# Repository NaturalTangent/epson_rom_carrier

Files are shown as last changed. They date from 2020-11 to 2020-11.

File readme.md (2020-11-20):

# Epson PX-8 / PX-4 ROM Carrier

Andy Anderson 2020

This is a 3d printable ROM carrier for mounting ROMs in the capsule sockets of the Epson PX-8 and PX-4 portable computers.

You may need to tweak some of the measurements (near the top of RomCapsule.scad) if your 3d printer performs differently to mine, or your ROM sockets have different tollerances (I have 2 PX-8 and the fit is tighter on one of them). It can help to chamfer the sharp edges on the bottom printed carrier with a scalpel.

The STL file can be generated by loading RomCapsule.scad into OpenSCAD (https://www.openscad.org/).

When printing you will need to enable supports to allow the horizontal tabs to print successfully.

For info:

One of my PX-8 has the following part numbers;

* ROM socket: 8878 28S MOLEX 5
* ROM carrier: MOLEX 5 8878

The other has;

* ROM socket: 5500 28 8878 MXJ 2
* ROM carrier: MXJ 4 5501

The MOLEX carrier is a tight fit in the MXJ socket. I based the measurement for this reproduction on the MXJ carrier.

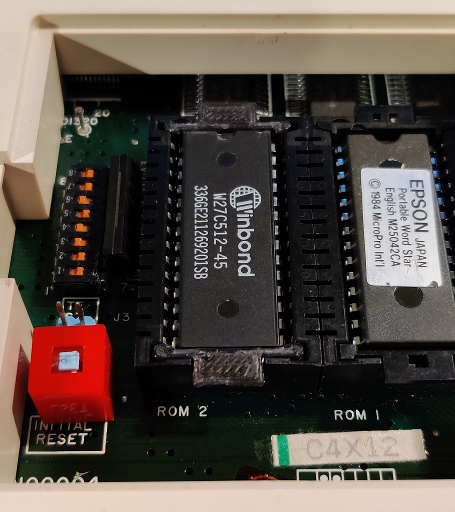
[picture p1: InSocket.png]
In Socket

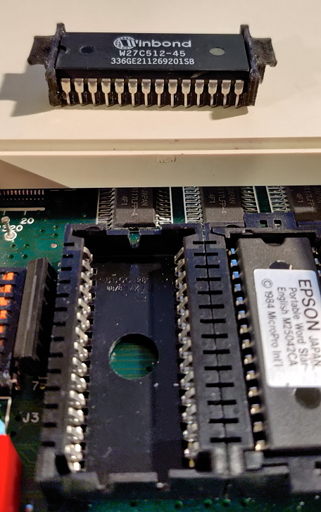
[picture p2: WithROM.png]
With ROM

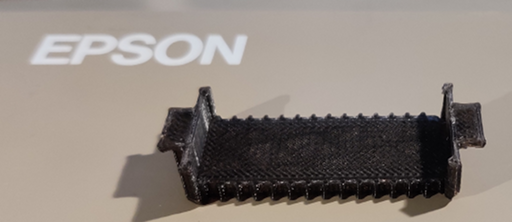
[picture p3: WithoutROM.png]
Without ROM


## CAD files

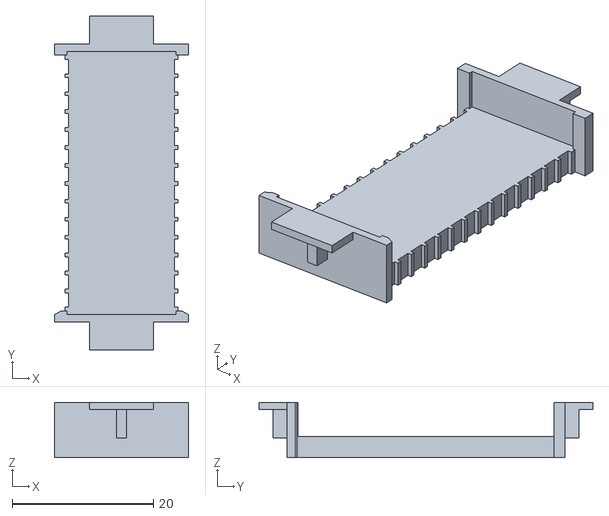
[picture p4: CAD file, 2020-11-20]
RomCapsule.stl
19.0 x 47.3 x 7.80

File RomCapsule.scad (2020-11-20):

/*
This is a 3d printable ROM carrier for mounting ROMs in the capsule sockets of the Epson PX-8 and PX-4 computers.

When printing you will need to enable supports to allow the horizontal tabs to print successfully.

Andy Anderson 2020
*/

// Dimension of the flat base
base_width = 16.0;
base_depth = 37.3;
base_height = 3;

// The distance between centres of the IC legs
pin_spacing = 2.54;

// Count of pins per side of the IC
pin_count = 14;

// IC leg dimension
pin_width = 2;
pin_clearance = 0.1;


// The gap cut into the base for each IC leg
pin_cut_depth = 0.5;
pin_gap = pin_width + pin_clearance;

// The size of the non-cut space between each IC leg
pin_non_gap = pin_spacing - pin_gap;

// The total base length that needs cuts for IC legs (easier to centre it)
active_pin_area = ((pin_count-1) * pin_non_gap) + (pin_count * pin_gap);
pin_start = (base_depth - active_pin_area)/2;

// The end wall dimensions
end_width = 19;
end_depth = 1;
end_height = 7.8;

// End wall strengthening bar dimensions
strength_width = 1.8;
strength_depth = 1.5;
strength_height = end_height;

// The dimensions of the flat tab on top of each end wall
tab_width = 9;
tab_depth = 4;
tab_height = 1;

// The dimensions of the locating tangs on each end wall
tang_width = 1.4;
tang_depth = 2;
tang_height = 4;


module base()
{
    difference()
    {
        cube([base_width, base_depth, base_height]);
        for(leg = [0: 1: pin_count-1])
        {
            translate([-pin_cut_depth, pin_start+(leg*pin_spacing), -1])
                cube([pin_cut_depth*2, pin_width, base_height+2]);
            
            translate([base_width-pin_cut_depth, pin_start+(leg*pin_spacing), -1])
                cube([pin_cut_depth*2, pin_width, base_height+2]);
        }
    }
}

// End with single tang and chamfered strengtheners
module end1()
{
    union()
    {
        // End wall
        cube([end_width, end_depth, end_height]);
        
        // Wall strength - with hacky chamfer
        hull()
        {
            cube([strength_width/2, end_depth, strength_height]); 
            translate([strength_width/2, 0, 0])
                cube([strength_width/2, strength_depth, strength_height]);        
        }
        
        hull()
        {
            translate([end_width-strength_width/2, 0, 0])
                cube([strength_width/2, end_depth, strength_height]); 
            translate([end_width-strength_width, 0, 0])
                cube([strength_width/2, strength_depth, strength_height]);
        }
                
        // Horizontal tab
        translate([end_width/2 - tab_width/2, -tab_depth, end_height-tab_height])
            cube([tab_width, tab_depth, tab_height]);
        
        // Single tang
        translate([end_width/2 - tang_width/2, -tang_depth, end_height-tang_height-tab_height])
            cube([tang_width, tang_depth, tang_height]);
    }
}

// End with double tang
module end2()
{
    union()
    {
        // End wall
        cube([end_width, end_depth, end_height]);
       
        // Wall strengthener
        cube([strength_width, strength_depth, strength_height]);
        
        translate([end_width-strength_width, 0, 0])
            cube([strength_width, strength_depth, strength_height]);
        
        // Horizontal tab
        translate([end_width/2 - tab_width/2, -tab_depth, end_height-tab_height])
            cube([tab_width, tab_depth, tab_height]);
        
        // double tangs
        translate([end_width/2-tab_width/2, -tang_depth, end_height-tang_height-tab_height])
            cube([tang_width, tang_depth, tang_height]);
        
        translate([(end_width/2+tab_width/2)-tang_width, -tang_depth, end_height-tang_height-tab_height])
            cube([tang_width, tang_depth, tang_height]);
    }
}

module carrier()
{
    union()
    {
        translate([0, -end_depth, 0])
            end1();
        
        translate([(end_width-base_width)/2, 0, 0])
            base();
        
        translate([end_width, base_depth + end_depth, 0])
            rotate(a = [0, 0, 180])
                end2();
    }
}





carrier();

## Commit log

2020-11-19 Initial version of epson PX-8 ROM carrier.
    [RomCapsule.scad, RomCapsule.stl]
2020-11-19 Tweaked sizes for better fit.
    [RomCapsule.scad, RomCapsule.stl]
2020-11-19 Added chamfers to single tang end.
    [RomCapsule.scad, RomCapsule.stl]
2020-11-20 More tweaking of dimensions for MOLEX sockets.
    [RomCapsule.scad, RomCapsule.stl]
